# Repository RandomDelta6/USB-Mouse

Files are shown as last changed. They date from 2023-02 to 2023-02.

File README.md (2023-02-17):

# Introduction
This is a basic USB mouse PCB based on the PAW3526D8-FJY2 Sensor in 8P SDIP 10x12.5 mm Package. It features 800 dpi resolution. The PCB is designed to be extremely cost efficient and resilient to dust interference. It features less than 80mA Active power draw and less than 10mA Idle draw. It uses an optical rotary encoder for accurate scroll count with <0.3% error rate. It uses USB 2.0 interface and complies with USB power Suspend Feature. The high tracking frequency allows it to measure even fast swipes accurately with less than 2% creepage even under suboptimal tracking conditions. 

Sensor Pixel Dump of pictures on different surfaces:  
 

TLDR: A basic USB mouse with left, right and middle click with a scroll wheel with enough performance and reliability to be used as a daily driver for office work. It has a fixed native dpi of 800 and no fancy edpi or dpi switching capabilities. Firmware is integrated in the PAW3526D8-FJY2 sensor and comes preflashed on the chip.

# Optical Sensor
The Optical Sensor Chosen for this PCB is PAW3526D8-FJY2, which is an MCU cum Sensor unit. It offers a small footprint and simple pinout for easy configuration and a space efficient and cost effective board layout.
## Description
PAW3526D8-FJY2 is based on optical navigation technology, which measures changes in position by optically acquiring sequential surface images (frames) and mathematically determining the direction and magnitude of movement. The sensor is housed in an 8-pin staggered dual inline package (DIP). It is designed for use with the M1 OptilensBis 02  03 Focussing Lens and the 003091-0000 SZ260 LED Clip, providing an optical mouse solution that is compact and affordable. There are no moving
parts, so precision optical alignment is not required, thereby facilitating high volume assembly.

## Theory of Operation
The PAW3526D8-FJY2 is based on Optical Navigation Technology. It contains an Image Acquisition System (IAS), a Digital Signal Processor (DSP). The IAS acquires microscopic surface images via the lens and illumination system. These images are processed by the DSP to determine the direction and distance of motion

## Features
• Precise optical navigation technology  
• Small form factor (10 mm x 12.5 mm footprint)  
• No mechanical moving parts   
• Complete 2D motion sensor  
• USB interface for simple design  
• Smooth surface navigation  
• Frame speed up to 3000 fps 
• Accurate motion up to 12 ips  
• 800 dpi resolution  
• High reliability   
• High speed motion detector   
• Wave solderable   
• Single 5.0 volt power supply  
• <50mA Active power draw
• <5mA Idle power draw
• Conforms to USB suspend mode specifications  
• Power conservation mode during times of no movement   
• 8-pin staggered dual inline package (DIP)  
• -30°C to 80°C Standard Operating Range

Package Specifications:  
 

# Schematic
 

# PCB
   

PCB Copper Trace View



PCB Front View



PCB Back View

# Usage

## PCB Assembly 
1.Wave solder the entire assembly in a no-wash solder process utilizing solder fixture.   
2.Insert the sensor and all other electrical components into PCB. Components marked NC in Component Glossary should be ignored. Note: Pin 1 of the sensor should always be the reference point of mechanical cutouts.    
3.Reflow THT Components which include the illumination LEDs, Optical Rotary Encoder, Switches, Jumpers and PAW3526D8-FJY2 Sensor before reflowing SMD components over hot air.   
## Capacitor Overview
• All capacitor footprints are for 0603 Imperial Footprint   
• The 0.1 uF caps must be ceramic.   
• Caps should have less than 5 nH of self inductance   
• Caps should have less than 0.2 ohms ESR   
• MLCC Surface mount parts are recommended   
## Overview of Optical Mouse Sensor Assembly
The PAW3526D8-FJY2 sensor is designed for mounting on a through hole PCB, looking down. There is an aperture stop and features on the package that align to the lens. M1 OptilensBis 02  03 Focussing Lens provides optics for the imaging of the surface as well as illumination of the surface at the
optimum angle. Features on the lens align it to the sensor, base plate, and clip with the LED. The lens also has a large round flange to provide a long creepage path for any ESD events that occur at the opening of the base plate. The 003091-0000 SZ260 clip holds the LED in relation to the lens. The LED’s leads must be formed first before inserting into the clip. Then, both LED and clip is loaded on the PCB. The clip interlocks the sensor to the lens, and through the lens to the alignment features on the base plate. A 940nm IR LED of sufficient brightness should be used for illumination.

   


## Product Assembly Considerations
Install the LED Clip on the Sensor Illumination LED. Insert the Retention Clip on the Lens into the slot in the LED  Clip and fold up the assembly. Ensure the lens focal point aligns with the sensor aperture. Guide features or adhesive maybe used on the baseplate to enure the lens assembly stays over the sensor aperture at optimum focus. The sensor aperture ring should self-align to the lens. The optical position reference for the PCB is set by the base plate and lens. Note that the PCB motion due to button presses must be minimized to maintain optical alignment. There MUST be a feature in the top case to press down onto the clip to ensure all components are interlocked to the correct vertical height. Note that the lens
material is polycarbonate and therefore, cyanoacrylate based adhesives or other adhesives that may damage the lens should NOT be used.

## Reference Pictures
 

LED Clip 003091-0000 SZ260

 

M1 OptilensBis 02  03 Focussing Lens

 

Scroll Wheel Assembly ( Wheel with 60 evenly spaced slits)

 

Reference PCB Top (Back)

 

Reference PCB Bottom (Front)

 

Reference PCB Bottom with Lens and LED Clip installed (Front)

 

Reference PCB In Reference Housing with Scroll Wheel Assembly in Place

# Notes

This PCB is based on the Mouton 1D CR PCB by Logitech found in their popular B100 Mice. This PCB is designed to be a drop in replacement with appropriate guide holes and retention feature placements.

This project has been made with Kicad 5.1.10

While exporting for fabrication the back solder mask layer may be ignored to save on manufacturing costs as it serves no purpose. Through holes may also be replaced with npth and pads on front side of pcb only to reduce cost further.

# Regulatory Information
• Passes EN61000-4-4/IEC801-4 EFTB tests when assembled into a mouse with shielded cable.    
• UL flammability level UL94 V-0.    
• Provides sufficient ESD creepage/clearance distance to avoid discharge up to 15 kV.    
• CLASS 1 LED Product   
• Complies with Canada ICES-003, Class B      

# Disclaimer
I do not assume any liability for the materials, information and opinions provided on, or available through, this project. I disclaim any liability for injury, death or damages resulting from the use thereof.

# Licensing
All PCB design files and hardware are released under the [Creative Commons Attribution Share Alike 4.0 license](https://choosealicense.com/licenses/cc-by-sa-4.0/).

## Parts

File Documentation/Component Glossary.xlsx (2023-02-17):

List of Materials
Sl. No. | Notation | Footprint | Value | Particulars | Remarks
1 | C8 | C_0603 |  | 0.01uF | MLCC
2 | C9 | C_0603 |  | 0.01uF | MLCC
3 | C11 | C_0603 |  |  | NC
4 | C12 | C_0603 |  | 0.1uF | MLCC
5 | C13 | C_0603 |  |  | NC
6 | C14 | C_0603 |  | 4.7uF | MLCC
7 | C15 | C_0603 |  | 0.1uF | MLCC
8 | R7 | R_0603 | R 270
9 | R8 | R_0603 | R 270
10 | R9 | R_0603 | R 303
11 | R10 | R_0603 | R 303
12 | C16 | C_0603 |  |  | NC
13 | R11 | R_0603 | R 303
14 | R12 | R_0603 | R 330
15 | R13 | R_0603 | R 105
16 | R14 | DIN0207 | R 1500ohm ± 5%
17 | R15 | R_0603 | R 1R0
18 | R16 | R_0603 | R 000
19 | R17 | R_0603 |  |  | NC
20 | U1 | 8P SDIP 10x12.5 mm | PAW3526D8-FJY2 | H9165632C | Sensor cum MCU
21 | SW1 | SPDT_SW | 15A 125V | Kailh SF19YA
22 | SW2 | SPDT_SW | 15A 125V | Kailh SF19YA
23 | SW3 | SPDT_SW | 15A 125V | Himake
24 | JP1 | DIN0207 | 0 ohm
25 | JP2 | DIN0207 | 0 ohm
26 | JP3 | DIN0207 | 0 ohm
27 | JP4 | DIN0207 | 0 ohm
28 | LD1 |  |  |  | Optical Rotary Encoder Pair (https://www.aliexpress.com/item/4000184464797.html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)
29 | LD2 |  | 1.4V 100mA | 940 nm IR | Infrared Lamp (https://www.aliexpress.com/item/32224584146.html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)
30 | LQI |  |  |  | Optical Rotary Encoder Pair (https://www.aliexpress.com/item/4000184464797.html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)
31 | J1 |  |  | JST 2.00MM PITCH 5 PIN

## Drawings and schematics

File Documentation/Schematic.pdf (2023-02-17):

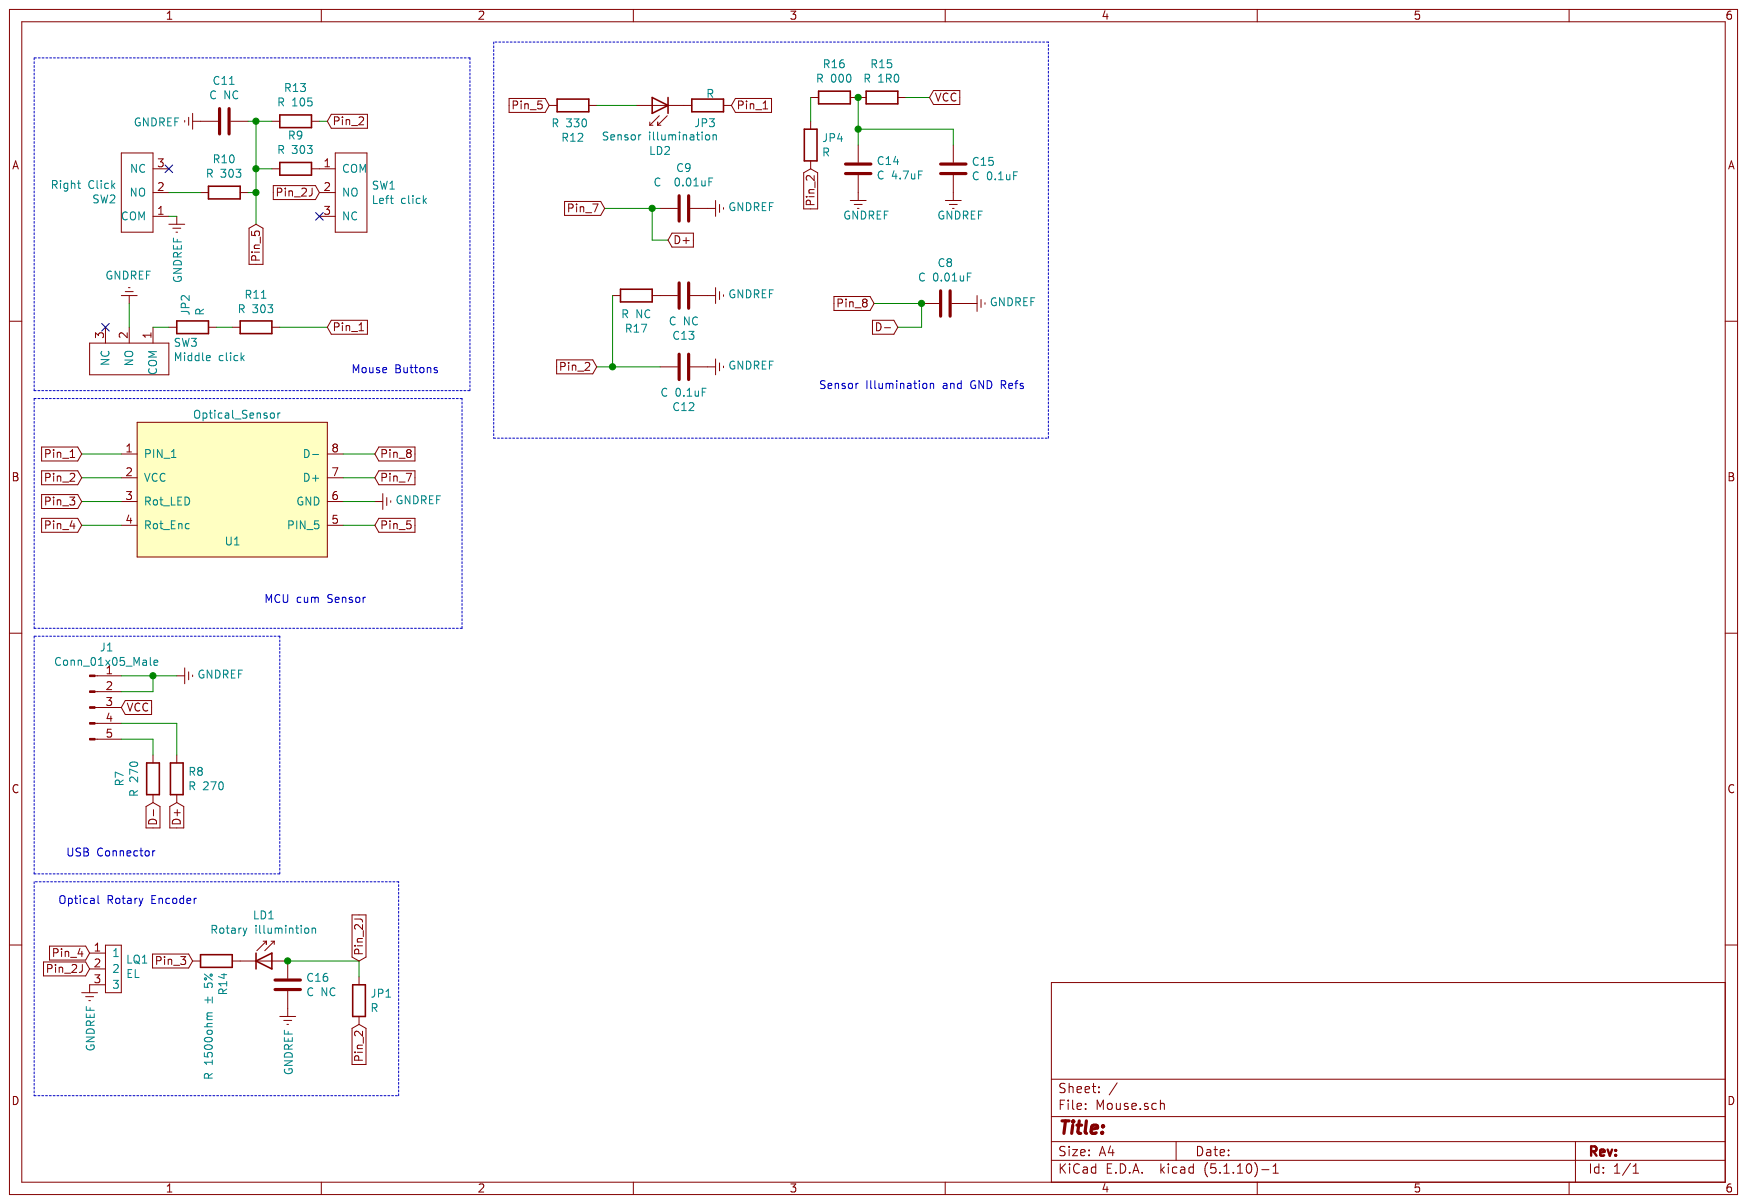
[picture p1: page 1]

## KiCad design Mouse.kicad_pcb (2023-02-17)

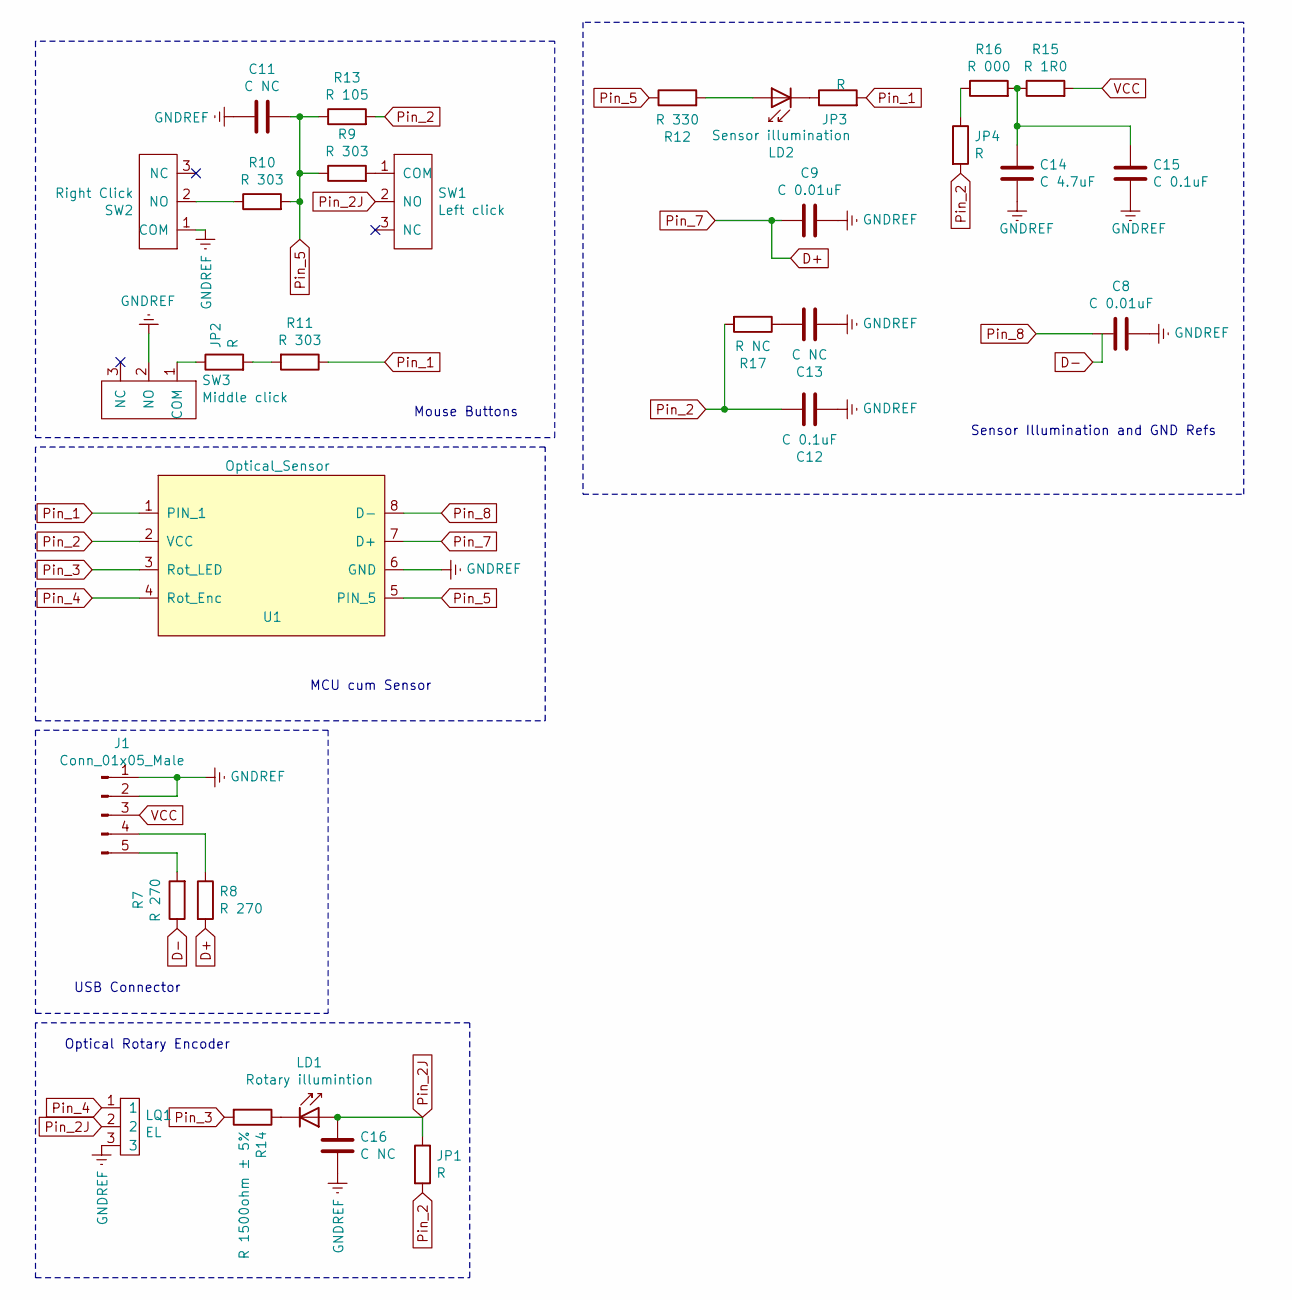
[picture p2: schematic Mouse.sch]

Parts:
C8, C9: C 0.01uF; R_0603_1608_Logi
C11, C13, C16: C NC; R_0603_1608_Logi
C12, C15: C 0.1uF; R_0603_1608_Logi
C14: C 4.7uF; R_0603_1608_Logi
J1: Conn_01x05_Male; JST_Conn
JP1, JP2, JP3, JP4: R; JP_Axial_DIN0207_L6.3mm_D2.5mm_P10.16mm_Horizontal
LD1: Rotary illumintion; Rot_LED
LD2: Sensor illumination; LED_Sensor
LQ1: EL; LQ1
R7, R8: R 270; R_0603_1608_Logi
R9, R10, R11: R 303; R_0603_1608_Logi
R12: R 330; R_0603_1608_Logi
R13: R 105; R_0603_1608_Logi
R14: R 1500ohm ± 5%; JP_Axial_DIN0207_L6.3mm_D2.5mm_P10.16mm_Horizontal
R15: R 1R0; R_0603_1608_Logi
R16: R 000; R_0603_1608_Logi
R17: R NC; R_0603_1608_Logi
SW1: Left click; SPDT_Switch
SW2: Right Click; SPDT_Switch
SW3: Middle click; SPDT_Switch
U1: Optical_Sensor; Sensor

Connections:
D+: C9.1, R8.2, U1.7 (D+)
D-: R7.1
GNDREF: C8.2, C9.2, C11.1, C12.1, C13.1, C14.1, C15.2, C16.2, J1.1, J1.2, LQ1.3, SW2.1 (COM), SW3.2 (NO), U1.6 (GND)
unnamed: C13.2, R17.1
unnamed: C14.2, C15.1, R15.1, R16.2
unnamed: J1.4, R8.1
unnamed: J1.5, R7.2
unnamed: JP2.1, SW3.1 (COM)
unnamed: JP2.2, R11.2
unnamed: JP3.1, LD2.1 (K)
unnamed: JP4.1, R16.1
unnamed: LD1.1 (K), R14.1
unnamed: LD2.2 (A), R12.2
unnamed: R9.2, SW1.1 (COM)
unnamed: R10.1, SW2.2 (NO)
Pin_1: JP3.2, R11.1, U1.1 (PIN_1)
Pin_2: C12.2, JP1.2, JP4.2, R13.2, R17.2, U1.2 (VCC)
Pin_2J: C16.1, JP1.1, LD1.2 (A), LQ1.2, SW1.2 (NO)
Pin_3: R14.2, U1.3 (Rot_LED)
Pin_4: LQ1.1, U1.4 (Rot_Enc)
Pin_5: C11.2, R9.1, R10.2, R12.1, R13.1, U1.5 (PIN_5)
Pin_8: C8.1, U1.8 (D-)
VCC: J1.3, R15.2

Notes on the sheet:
Optical Rotary Encoder
USB Connector
MCU cum Sensor
Mouse Buttons
Sensor Illumination and GND Refs

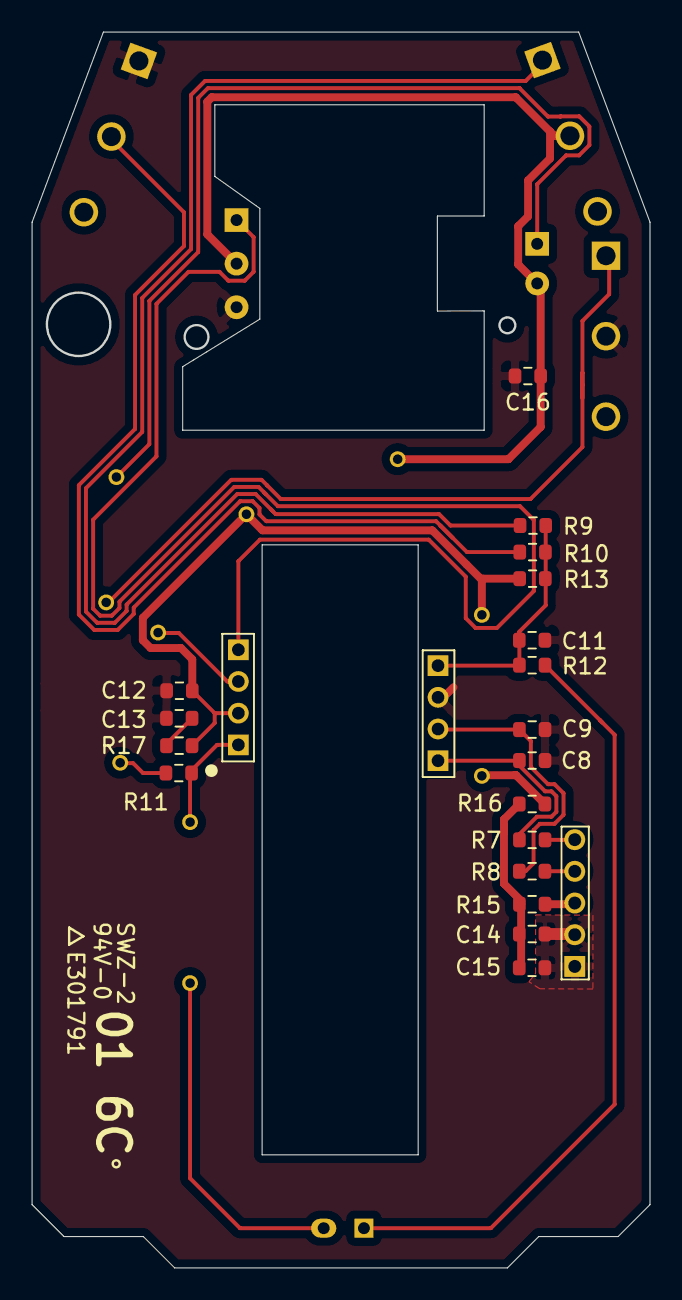
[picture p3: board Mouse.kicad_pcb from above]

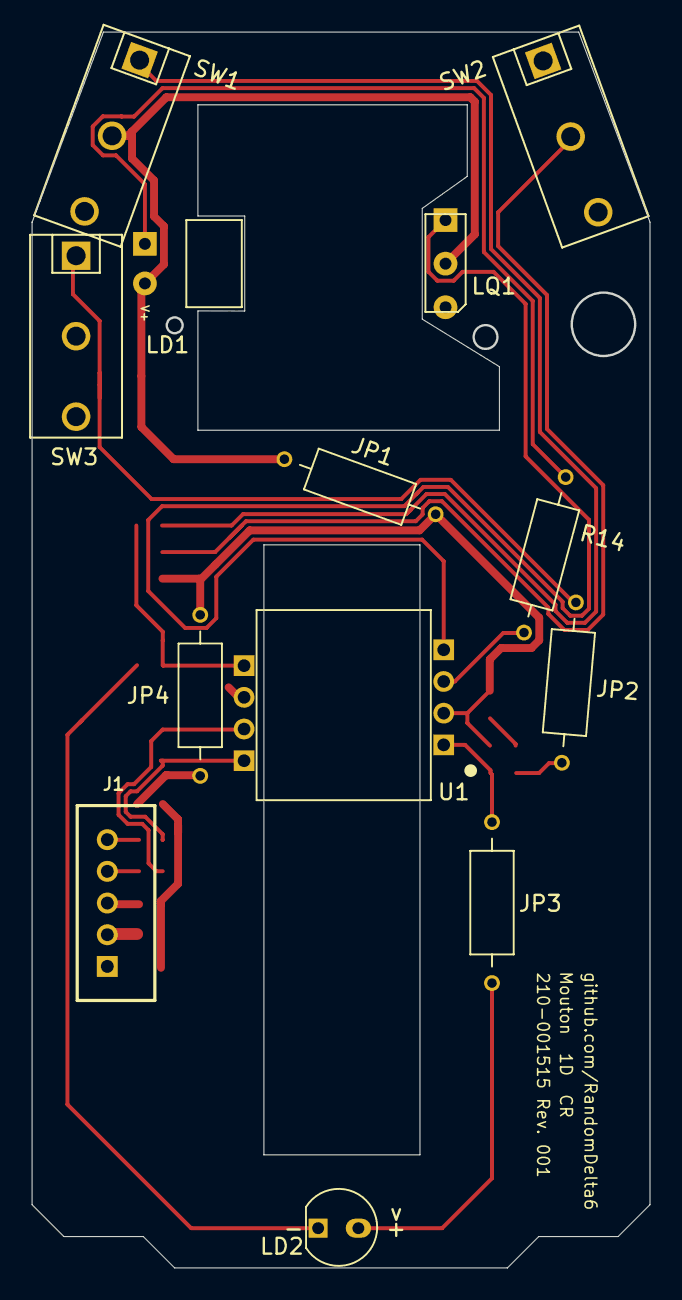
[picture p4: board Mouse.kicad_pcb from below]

Board: 2 copper layers, 39.0 x 78.0 mm, 31 parts (13 on the bottom side), 22 nets.

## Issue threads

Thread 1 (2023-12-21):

Please help me understand the optical rotary encoder circuit

wzkres, 2023-12-21:
Hi,

Thanks for this great open source mouse project, really learned a lot! I've been trying to understand how the mouse wheel work in the circuit, is LQ1 a dual phototransistor? How would the MCU sense wheel rotating direction with only one pin (one of the emitter?) connected to it?

Regards

RandomDelta6, 2023-12-22:
LQ1 is indeed a dual LDR. It detects which way the scroll wheel is moving by comparing the change in resistances across both the LDRs . Lets say there is no resistance change in either LDR. It means the scroll wheel is static. If resistance of LDR1 decreases while resistance of LDR 2 increases, it means that the level of illumination on LDR1 is increasing while its decreasing on LDR2 , let's say it corroborates to scrolling down. The opposite change in resistance across the LDRs will indicate scrolling in Up direction. The rate of change of resistance will indicate how fast the scroll wheel is being spun. It is necessary that the slits on the scroll wheel are spaced apart exactly as per specification so that under no circumstance would both LDRs be completely exposed or completely in shadow.

The chosen MCU has preflashed logic for filtering and decoding scroll logic based off analog output of LQ1. it is actually to two pins, pin 4 and pin 3 of the MCU. Pin 3 is also shared with the led, which allows the brightness to be varied with respect to output across one of the internal LDRs of LQ1 which allows it to figure the direction of rotation with more accuracy.

wzkres, 2023-12-22:
Thank you so much!

Closed 2023-12-22.

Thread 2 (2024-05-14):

PAW3526DB datasheet

NetBUG, 2024-05-14:
Hi,

I am a bit interested in digging a bit into optical chips cause I'm trying to make a robot with optical odometry (correction).

I've found a couple mice with PAW3512K and one with PAW3526B
The first chip is pretty well documented while the second is less known

Did you manage to find the datasheet for it?

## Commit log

2022-08-15 added footprints
    [Mouse.kicad_pcb, Mouse.sch]
2022-08-20 updated footprints
    [Mouse.kicad_pcb, Mouse.sch]
2023-02-08 Updated components
    [Mouse.kicad_pcb, Mouse.sch]
2023-02-09 created the inner and outer edge cuts
    [Mouse.kicad_pcb]
2023-02-11 optical sensor marker pushed to 14.5mm approx
    [Mouse.kicad_pcb]
2023-02-14 Updated layout
    [Mouse.kicad_pcb, Mouse.sch]
2023-02-15 Updated board layout
    [Mouse.kicad_pcb, Mouse.sch]
2023-02-15 Layout Updated
    [Mouse.kicad_pcb, Mouse.sch]
2023-02-17 Updated Schematics, Layout and Footprints
    [Component Glossary.xlsx, Mouse.kicad_pcb, Mouse.sch]
2023-02-17 Schematic Correction
    [Mouse.kicad_pcb, Mouse.sch]
2023-02-17 Fixed some copper traces, updated readme snaps
2023-02-17 Update Schematics
